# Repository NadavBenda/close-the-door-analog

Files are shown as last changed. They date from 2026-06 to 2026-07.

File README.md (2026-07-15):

# Close-the-Door Analog Reminder 🚪🔊

A small battery-powered analog reminder circuit for a shared-house door.

If the door is left open for more than a short delay, the circuit emits a gentle beep sequence as a reminder to close it. The design is intentionally implemented without a microcontroller, using discrete analog/timing logic.

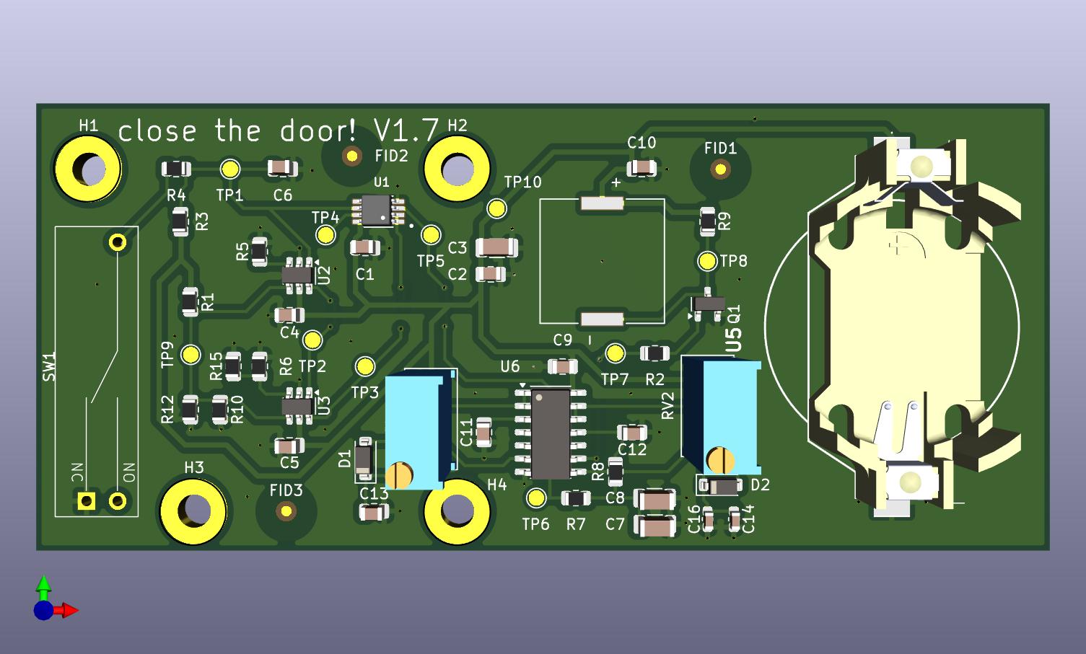
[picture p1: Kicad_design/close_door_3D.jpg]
PCB render


## Motivation

This project started from a real everyday problem: people passing through a shared hallway door often leave it open. Instead of using a software-heavy smart-home solution, the goal was to build a small, manufacturable analog PCB and practice the full hardware design flow independently.

## Design Goals

* Fully analog / no MCU
* Battery powered
* Low standby current
* Reed-switch door sensing
* Gentle, non-intrusive acoustic reminder
* Simple PCB suitable for low-cost fabrication and assembly
* Designed as a first independent end-to-end PCB project

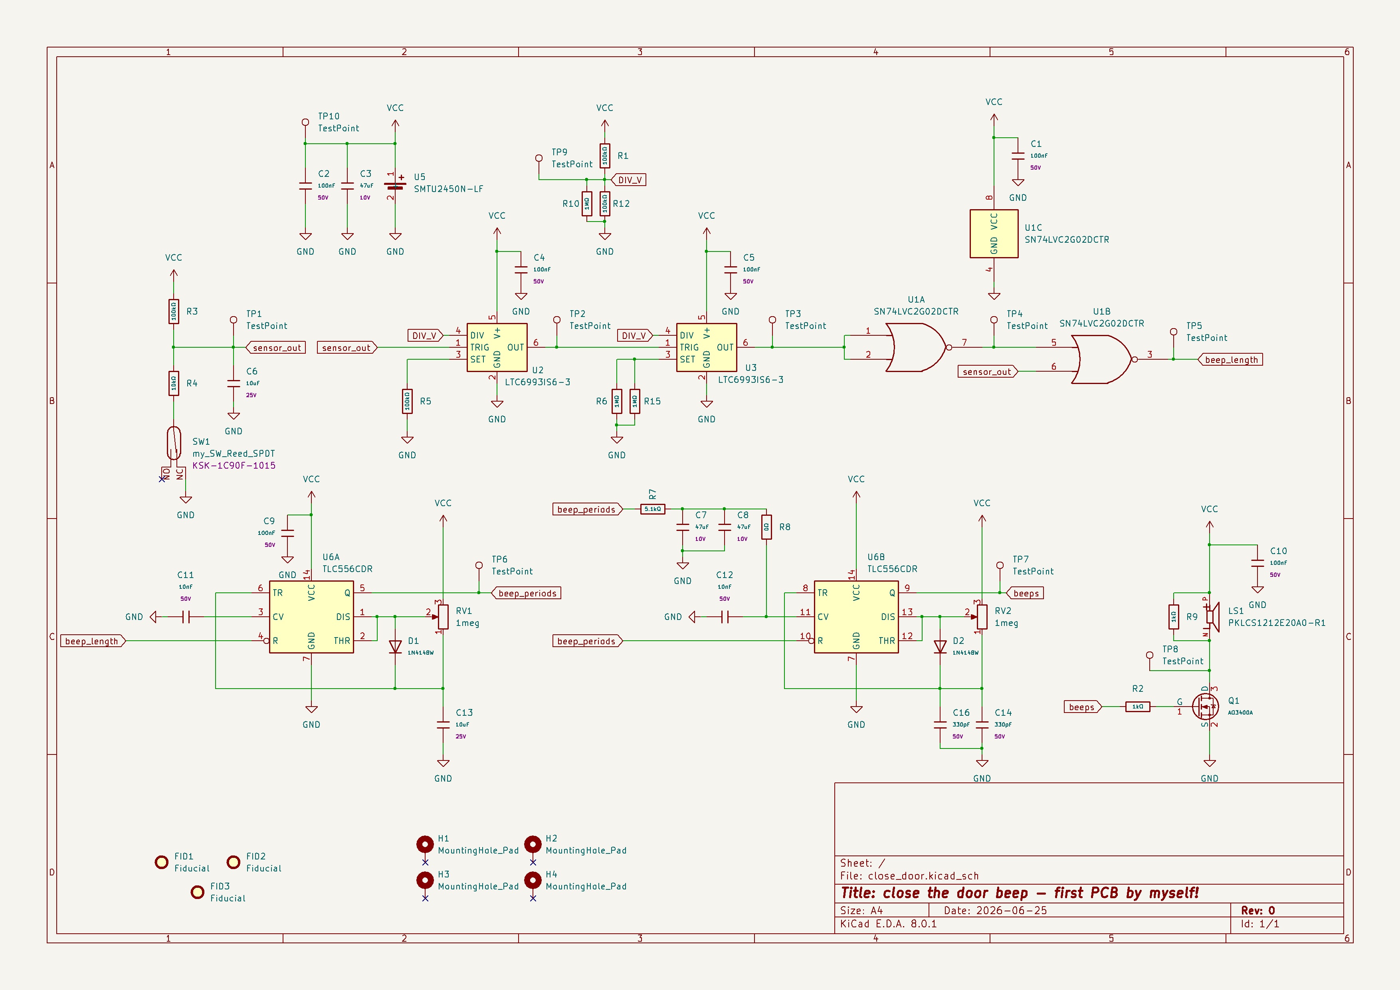
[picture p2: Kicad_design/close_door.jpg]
schematic render


## System Overview

The circuit consists of:

* Reed switch for door-state detection
* CMOS timer logic for delay and beep timing
* Logic gates for signal conditioning
* Passive piezo transducer for the sound output
* Coin-cell battery supply
* Test points for bring-up and debugging

Basic behavior:

```text
Door opens
→ delay timer starts
→ if condition is met
→ short beep sequence
→ silence
```

## Hardware

The board was designed in KiCad and sent to fabrication through JLCPCB.

Main design considerations included:

* Low standby current
* Mechanical placement of reed switch and magnet
* Decoupling for CMOS timing ICs
* Passive piezo drive
* Testability during bring-up
* Manufacturable footprints and BOM preparation

## Status

Assembled

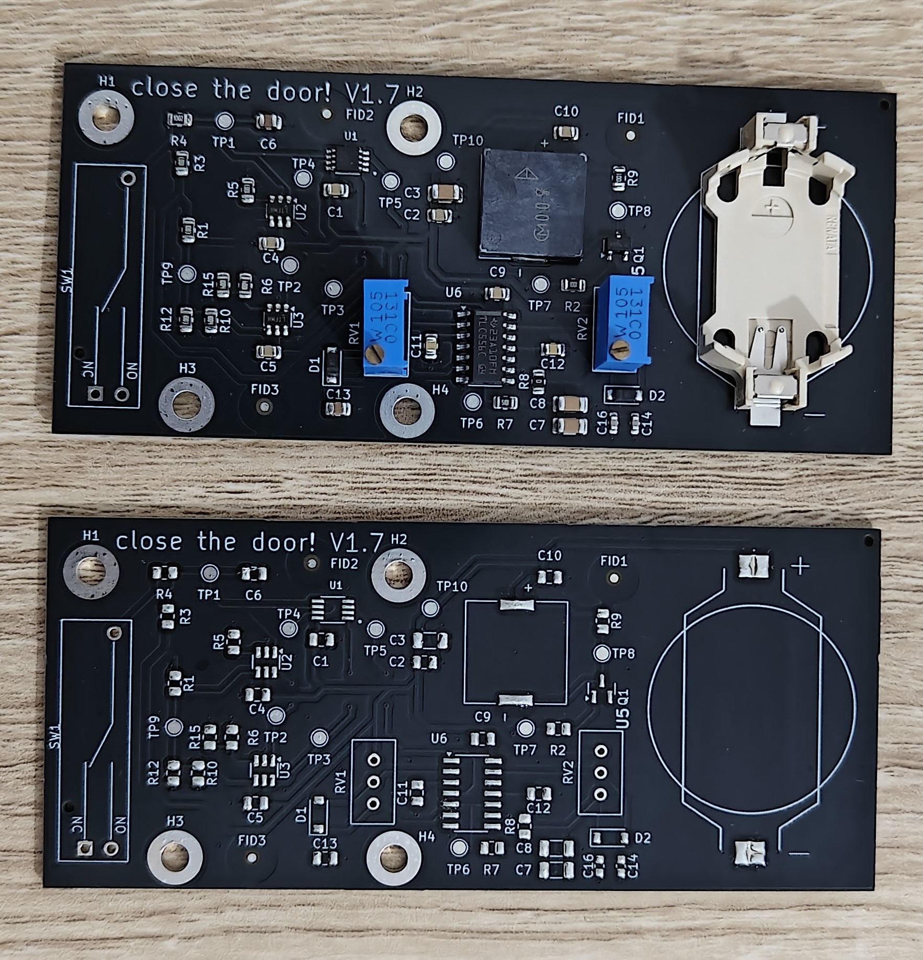
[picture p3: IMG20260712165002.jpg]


## Known Limitations 

Capacitor Discharge Time: Because the timing circuit is purely analog, the timing capacitor requires a brief period to discharge fully after the door is closed. If the door is cycled (opened and closed) in very rapid succession, the capacitor may remain partially charged, causing the subsequent alarm delay to trigger sooner than the configured duration.

## License

This project is shared for learning and reference

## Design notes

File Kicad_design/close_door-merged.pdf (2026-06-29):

# TP7 TestPoint GND

# R12 þÿ100k© GND

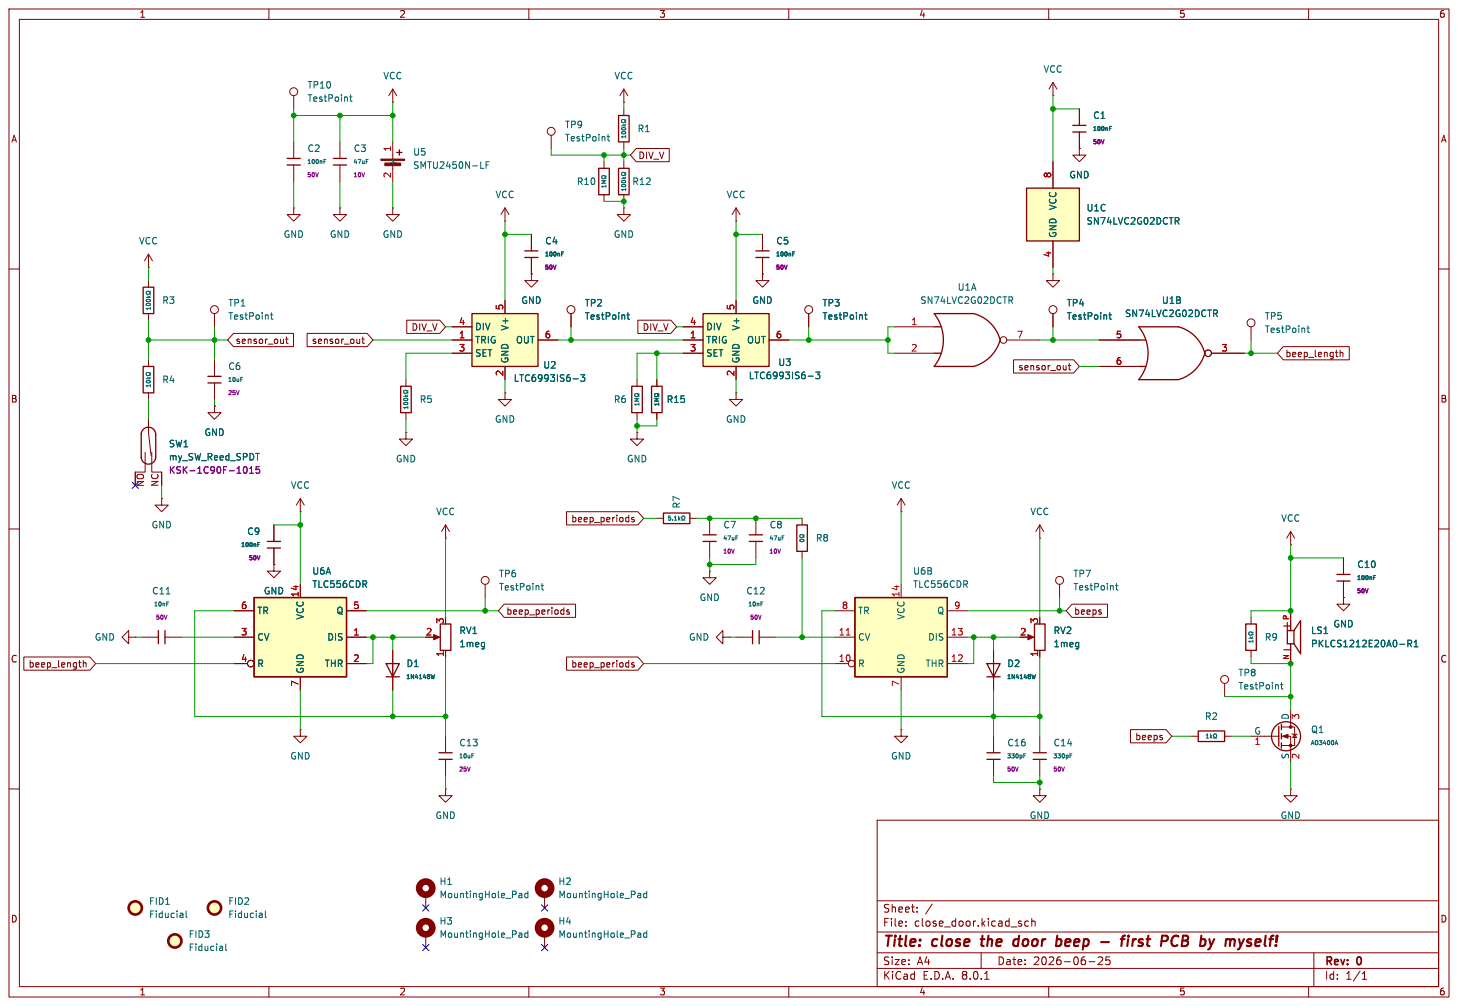
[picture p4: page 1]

5 OUT 6 GND TP3 TestPoint GND

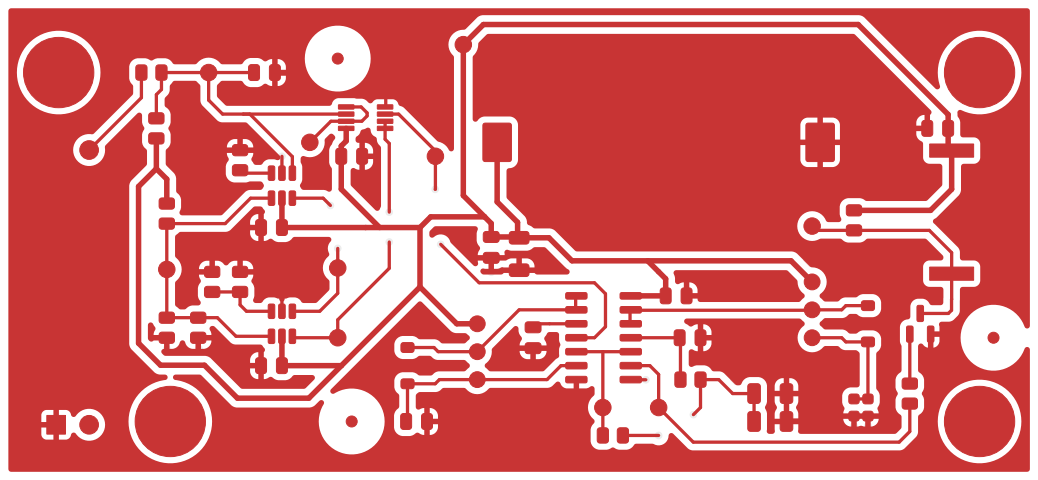
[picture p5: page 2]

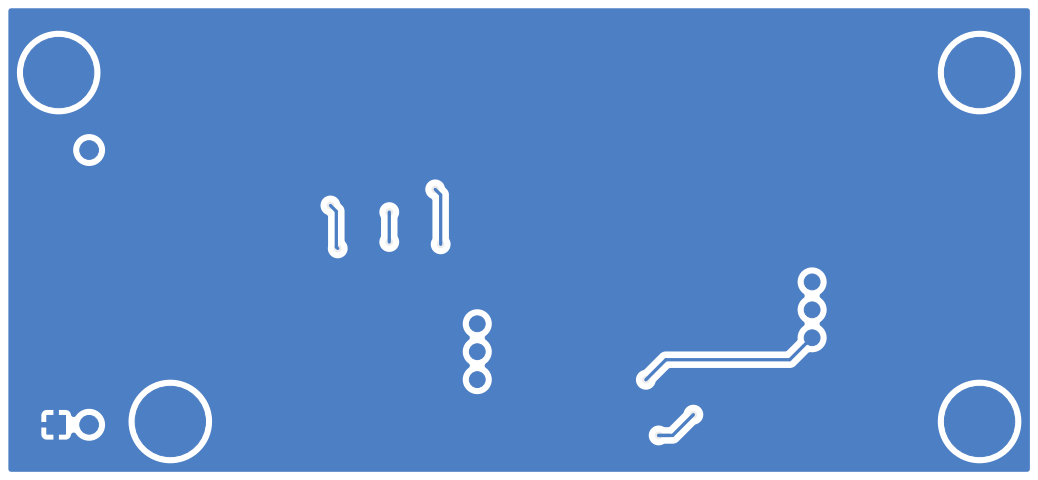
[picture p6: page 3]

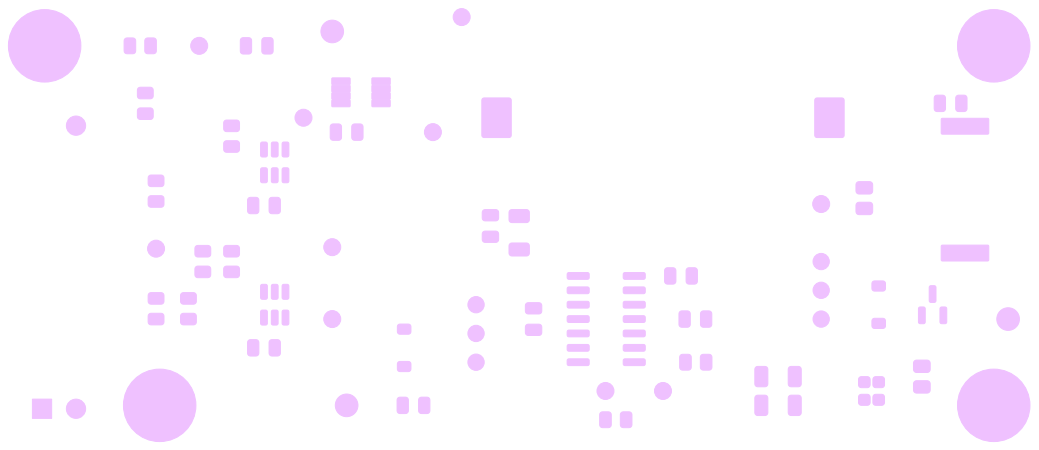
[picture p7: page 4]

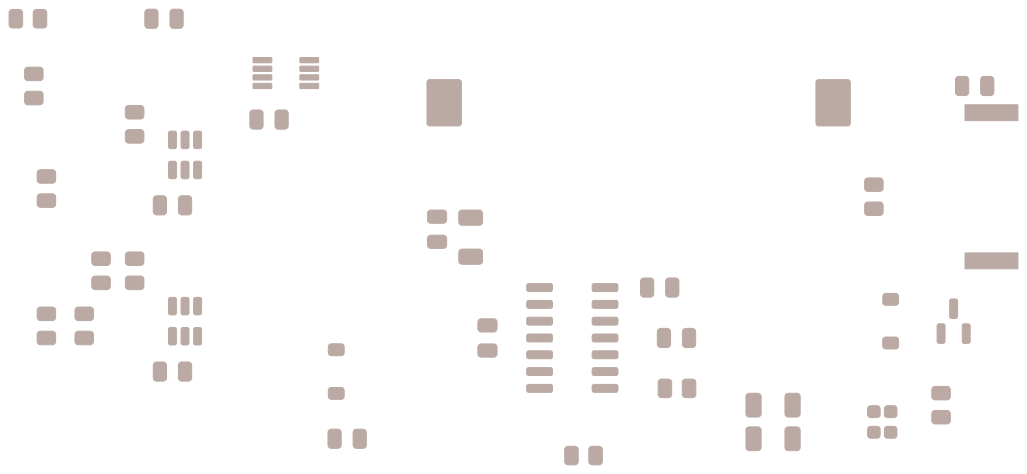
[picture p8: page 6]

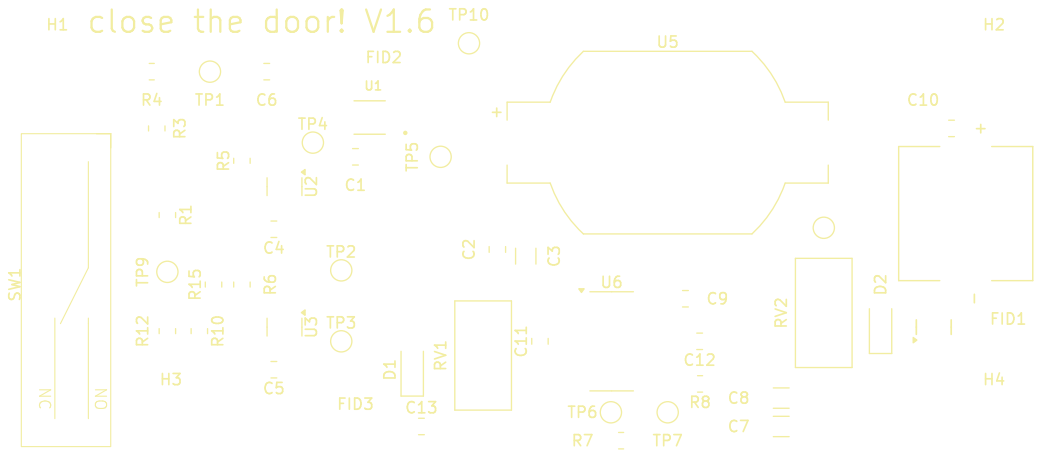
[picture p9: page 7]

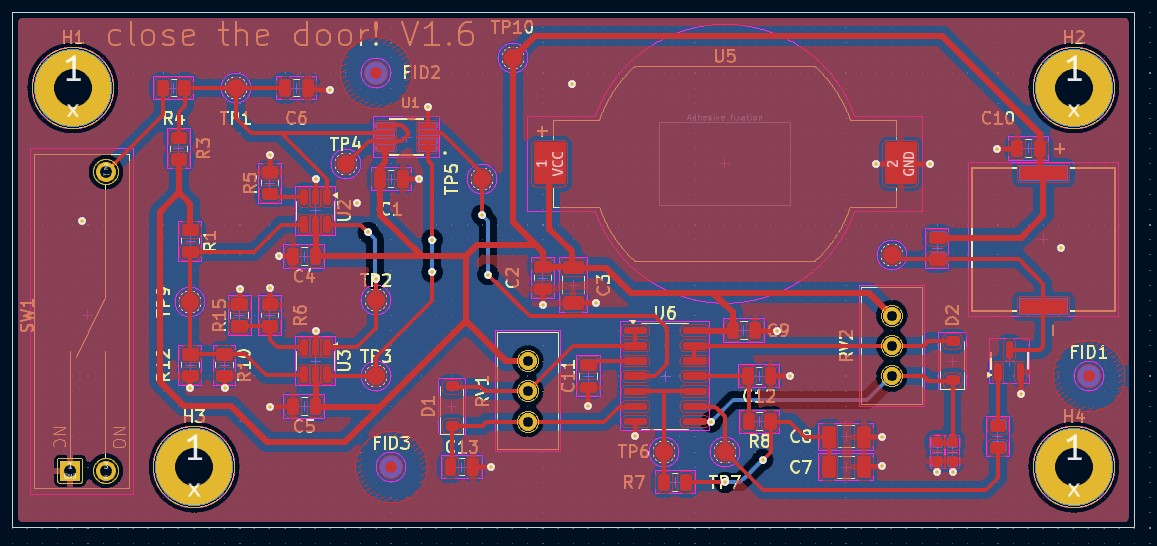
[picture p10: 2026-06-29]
Kicad_design/Screenshot_3.jpg

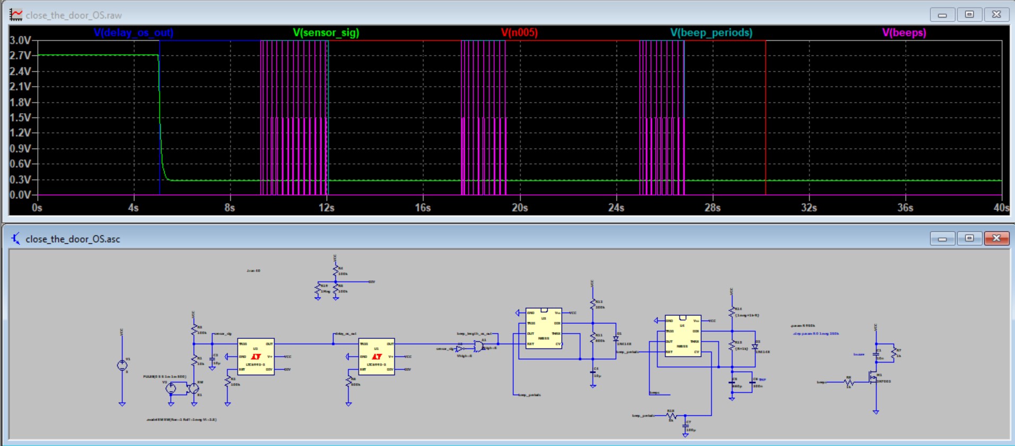
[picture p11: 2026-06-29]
LTspice_simulation/Screenshot_4.jpg

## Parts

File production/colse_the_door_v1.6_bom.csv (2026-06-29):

Designator | Footprint | Quantity | Value | LCSC Part #
C1, C10, C2, C4, C5, C9 | 0805 | 6 | 100nF | C49678
C11, C12 | 0805 | 2 | 10nF | C1710
C13, C6 | 0805 | 2 | 10uF | C15850
C14, C16 | C_0603 | 2 | 330pF | C1664
C3, C7, C8 | 1206 | 3 | 47uF | C96123
D1, D2 | D_SOD-123 | 2 | 1N4148W | C81598
LS1 | PKLCS1212E20A0-R1 | 1 | PKLCS1212E20A0-R1 | PKLCS1212E20A0-R1
Q1 | Q_SOT-23 | 1 | AO3400A | C20917
R1, R12, R3, R5 | 0805 | 4 | 100kΩ | C149504
R10, R15, R6 | 0805 | 3 | 1MΩ | C17514
R2, R9 | R_0805 | 2 | 1kΩ | C17513
R4 | 0805 | 1 | 10kΩ | C17414
R7 | 0805 | 1 | 5.1kΩ | C27834
R8 | 0805 | 1 | 0Ω | C17477
RV1, RV2 | Potentiometer_Bourns_3296W_Vertical | 2 | 1meg | C83687
SW1 | KSK-1C90F-1015 | 1 | my_SW_Reed_SPDT | KSK-1C90F-1015
TP1, TP10, TP2, TP3, TP4, TP5, TP6, TP7, TP8, TP9 | TestPoint_Pad_D1.5mm | 10 | TestPoint
U1 | SOP65P400X130-8N | 1 | SN74LVC2G02DCTR | C94600
U2, U3 | TSOT-23-6 | 2 | LTC6993IS6-3 | LTC6993IS6-3#TRMPBF
U5 | BatteryHolder_Renata_SMTU2032-LF_1x2032 | 1 | SMTU2450N-LF | C5443913
U6 | SOIC-14_3.9x8.7mm_P1.27mm | 1 | TLC556CDR | TLC556CDR

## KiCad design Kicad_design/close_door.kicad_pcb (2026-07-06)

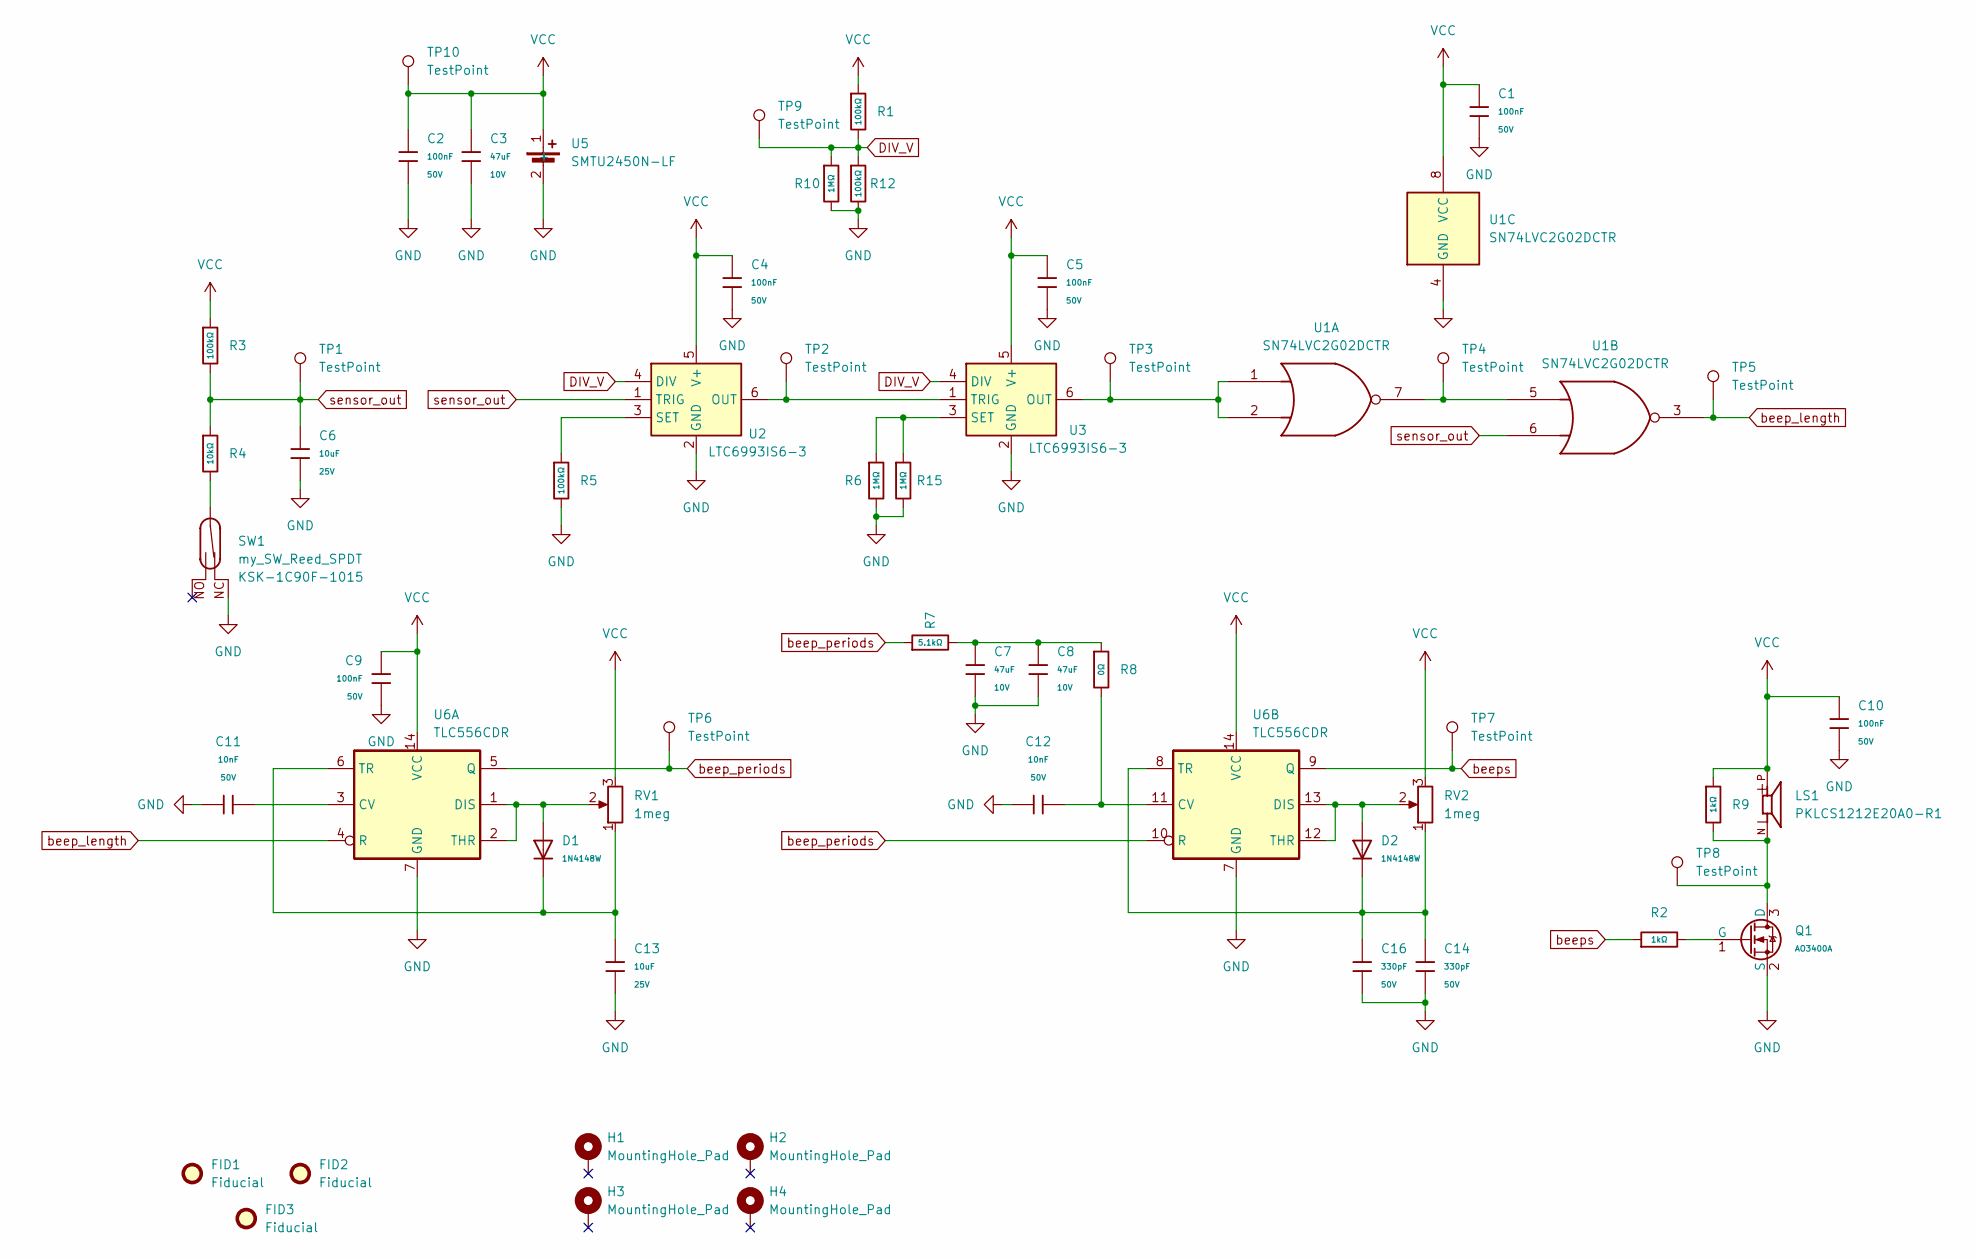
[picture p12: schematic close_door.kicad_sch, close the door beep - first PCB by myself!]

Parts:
C1, C2, C4, C5, C9, C10: 100nF; C_0805_2012Metric; Voltage Rated 50V; Tolerance ±10%; Part CC0805KRX7R9BB104; LCSC C49678
C3, C7, C8: 47uF; C_1206_3216Metric; Voltage Rated 10V; Tolerance ±20%; Part CL31A476MPHNNNE; LCSC C96123
C6, C13: 10uF; C_0805_2012Metric; Voltage Rated 25V; Tolerance ±10%; Part CL21A106KAYNNNE; LCSC C15850
C11, C12: 10nF; C_0805_2012Metric; Voltage Rated 50V; Tolerance ±10%; Part CL21B103KBANNNC; LCSC C1710
C14, C16: 330pF; C_0603_1608Metric; Voltage Rated 50V; Tolerance ±5%; Part CL10C331JB8NNNC; LCSC C1664
D1, D2: 1N4148W; D_SOD-123; Forward Voltage (Vf@If) 1V@50mA; Reverse Voltage (Vr) 75V; Part 1N4148W; LCSC C81598
FID1, FID2, FID3: Fiducial; Fiducial_1mm_Mask2mm_with_keepout
H1, H2, H3, H4: MountingHole_Pad; MountingHole_3.2mm_M3_Pad
LS1: PKLCS1212E20A0-R1; PARTREV January 22, 2018
Q1: AO3400A; SOT-23; Part AO3400A; LCSC C20917
R1, R3, R5, R12: 100kΩ; R_0805_2012Metric; Overload Voltage (Max) 150V; Tolerance ±1%; Part 0805W8F1003T5E; LCSC C149504
R2, R9: 1kΩ; R_0805_2012Metric; Overload Voltage (Max) 150V; Tolerance ±1%; Part 0805W8F1001T5E; LCSC C17513
R4: 10kΩ; R_0805_2012Metric; Overload Voltage (Max) 150V; Tolerance ±1%; Part 0805W8F1002T5E; LCSC C17414
R6, R10, R15: 1MΩ; R_0805_2012Metric; Overload Voltage (Max) 150V; Tolerance ±1%; Part 0805W8F1004T5E; LCSC C17514
R7: 5.1kΩ; R_0805_2012Metric; Overload Voltage (Max) 150V; Tolerance ±1%; Part 0805W8F5101T5E; LCSC C27834
R8: 0Ω; R_0805_2012Metric; Overload Voltage (Max) 150V; Tolerance ±1%; Part 0805W8F0000T5E; LCSC C17477
RV1, RV2: 1meg; Potentiometer_Bourns_3296W_Vertical; MPN 3296W-1-105LF; LCSC C83687
SW1: my_SW_Reed_SPDT; KSK-1C90F-1015; MPN KSK-1C90F-1015
TP1, TP2, TP3, TP4, TP5, TP6, TP7, TP8, TP9, TP10: TestPoint; TestPoint_Pad_D1.5mm
U1: SN74LVC2G02DCTR; SOP65P400X130-8N; MPN SN74LVC2G02DCTR; LCSC C94600
U2, U3: LTC6993IS6-3; TSOT-23-6; MPN LTC6993IS6-3#TRMPBF
U5: SMTU2450N-LF; SMTU2450N1LF; Mouser Part Number 614-SMTU2450N-LF.TR
U6: TLC556CDR; SOIC-14_3.9x8.7mm_P1.27mm; MPN TLC556CDR; LCSC C201587

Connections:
DIV_V: R1.2, R10.1, R12.1, TP9.1, U2.4 (DIV), U3.4 (DIV)
GND: C1.2, C2.2, C3.2, C4.2, C5.2, C6.2, C7.2, C8.2, C9.2, C10.2, C11.1, C12.1, C13.2, C14.2, C16.2, Q1.2 (S), R5.2, R6.2, R10.2, R12.2, R15.2, SW1.1, U1.4 (GND), U2.2 (GND), U3.2 (GND), U5.2 (-), U6.7 (GND)
unnamed: C7.1, C8.1, R7.2, R8.1
unnamed: LS1.N, Q1.3 (D), R9.2, TP8.1
unnamed: Q1.1 (G), R2.2
unnamed: R4.2, SW1.2
unnamed: TP4.1, U1.5, U1.7
unnamed: TP2.1, U2.6 (OUT), U3.1 (TRIG)
unnamed: R5.1, U2.3 (SET)
unnamed: TP3.1, U1.1, U1.2, U3.6 (OUT)
unnamed: R6.1, R15.1, U3.3 (SET)
unnamed: C11.2, U6.3 (CV)
unnamed: D1.2, RV1.2, U6.1 (DIS), U6.2 (THR)
unnamed: C13.1, D1.1, RV1.1, U6.6 (TR)
unnamed: C12.2, R8.2, U6.11 (CV)
unnamed: D2.2, RV2.2, U6.12 (THR), U6.13 (DIS)
unnamed: C14.1, C16.1, D2.1, RV2.1, U6.8 (TR)
VCC: C1.1, C2.1, C3.1, C4.1, C5.1, C9.1, C10.1, LS1.P, R1.1, R3.1, R9.1, RV1.3, RV2.3, TP10.1, U1.8 (VCC), U2.5 (V+), U3.5 (V+), U5.1 (+), U6.14 (VCC)
beep_length: TP5.1, U1.3, U6.4 (R)
beep_periods: R7.1, TP6.1, U6.5 (Q), U6.10 (R)
beeps: R2.1, TP7.1, U6.9 (Q)
sensor_out: C6.1, R3.2, R4.1, TP1.1, U1.6, U2.1 (TRIG)

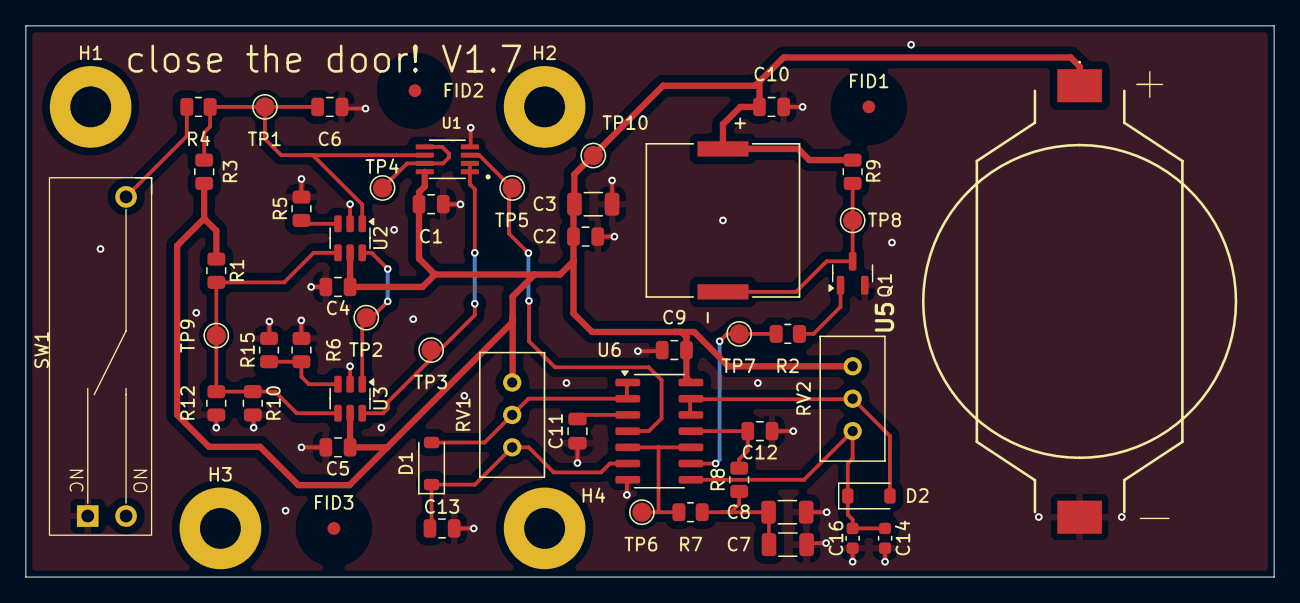
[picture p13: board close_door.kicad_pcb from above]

Board: 2 copper layers, 97.8 x 43.2 mm, 56 parts (0 on the bottom side), 22 nets.

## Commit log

2026-06-29 Update README with PCB image and formatting
    Added an image of the PCB design and reformatted the README for better clarity.
2026-06-29 Organize project files
    [close_door.kicad_pcb, close_door.kicad_sch, colse_the_door_v1.6_bom.csv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]
2026-07-15 Revise README with assembly status and image
    Updated README to reflect the assembly status and included an image.
